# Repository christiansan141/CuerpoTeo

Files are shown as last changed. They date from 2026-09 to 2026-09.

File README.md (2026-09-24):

# TEO CONTROL R1 - Carcasa

Carcasa impresa en 3D para la tarjeta TEO CONTROL R1 (RPI-TK), controlador de fajon termico.
Disenada en Autodesk Fusion (documento CARA_TEO, carpeta CLAUDE).

## Archivos

| Archivo | Contenido |
|---|---|
| `CARA_TEO.f3d` | Archivo fuente de Fusion (historial parametrico completo) |
| `CARA_TEO.step` | Cara + cuerpo en STEP (intercambio CAD) |
| `stl/TEO_CARA_Y_CUERPO.stl` | Ambas piezas orientadas para imprimir |
| `stl/TEO_CARA.stl` / `stl/TEO_CUERPO.stl` / `stl/TEO_CONTRAMARCO.stl` | Piezas por separado |

## Especificaciones

- Material: PETG
- Altura total: 28 mm (cara 2 mm + cuerpo 26 mm); 15.4 mm libres bajo la PCB
- Cara: 60 x 121.8 mm, ventana OLED 24 x 14 mm con esquinas R1.5 y borde suavizado R0.6
- Interior: 122 mm de largo (incluye compartimento del convertidor AC-DC)
- Paredes y fondo: 2 mm
- Union cara-cuerpo: escalon (holgura 0.2 mm/lado) + 4 tornillos M3 con insertos termicos (piloto 4.0 mm, prof. 10 mm), simetricos a 4.5 mm de cada borde
- Barrera de 1.1 mm entre convertidor AC-DC y tarjeta
- Salidas de cables por el fondo: 4 ranuras de 7.5 mm (simetricas)
- Anclajes para brida en la salida de 120 V (borneras)
- Marco de sujecion continuo (10 mm hacia afuera, 3 mm de espesor), 12 mm bajo la cara, con 16 huecos de 4 mm y nervios a 45 grados por encima
- Contramarco de 3 mm con los mismos 16 huecos: se atornilla bajo el marco y pellizca la tela del fajon
- Agujeros para buzzer y rejillas de ventilacion en la franja expuesta

## Impresion

- Cara: superficie visible sobre la cama
- Cuerpo: fondo sobre la cama (el marco necesita soporte)
- `stl/CARA_CUERPO_TEO.stl`, `stl/CARA_TEO.stl`, `stl/CUERPO_TEO.stl`, `stl/AGARRE_TEO.stl`: ya orientados y apoyados en Z=0
- `CUERPO_TEO.stl` y `CARA_CUERPO_TEO.stl` traen soportes integrados bajo el marco: 148 aletas de 0.8 mm cada 2.5 mm,
  0.2 mm por debajo del marco y 0.6 mm separadas de la pared. Imprimir con los soportes del laminador desactivados
  y retirar las aletas a mano
- Insertos termicos M3 con cautin a ~240 C (PETG)

## Pendientes

- NFC embebido detras del QR (bolsillo interno + pausa de capa)
- Aislamiento Kapton/papel pescado entre convertidor y rele si hace falta

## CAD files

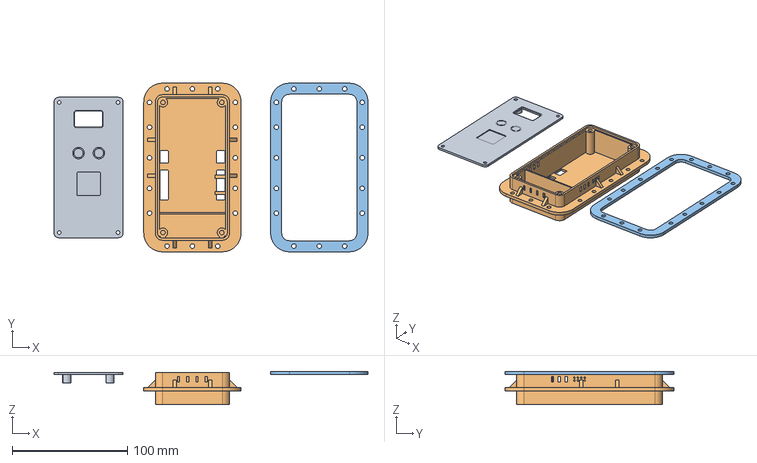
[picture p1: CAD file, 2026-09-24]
CARA_TEO.step
272.2 x 146.2 x 29.0 mm

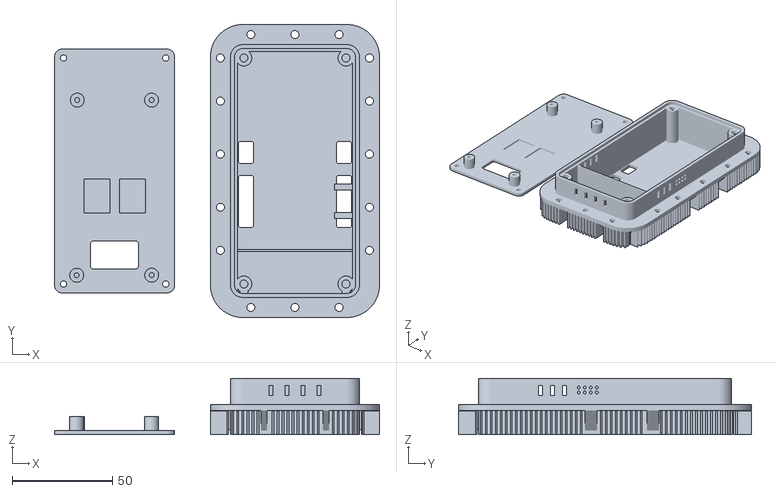
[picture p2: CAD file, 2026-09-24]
stl/CARA_CUERPO_TEO.stl
162.2 x 146.2 x 28.0

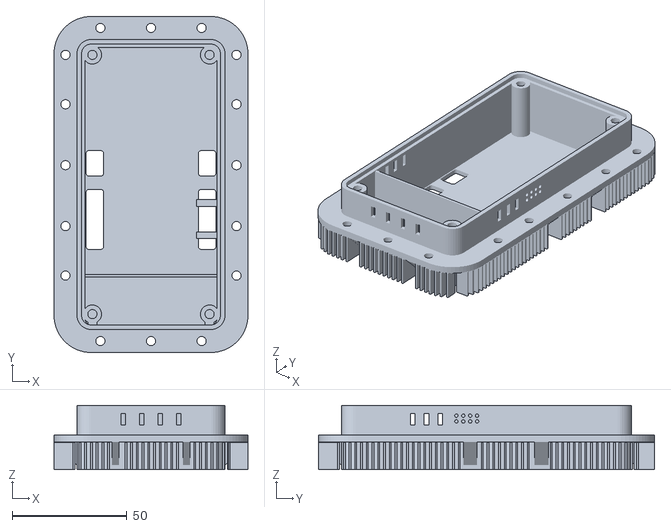
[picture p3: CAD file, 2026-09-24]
stl/CUERPO_TEO.stl
84.4 x 146.2 x 28.0

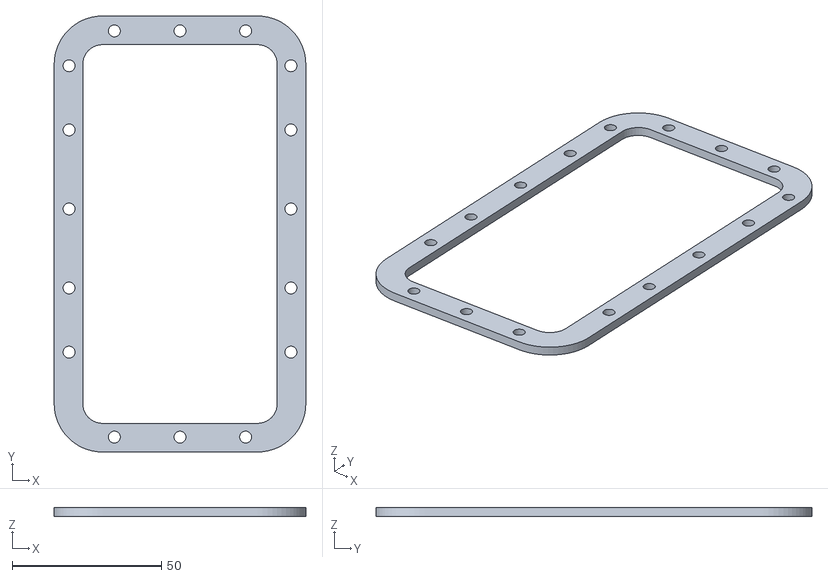
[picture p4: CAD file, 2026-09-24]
stl/AGARRE_TEO.stl
84.4 x 146.2 x 3.00

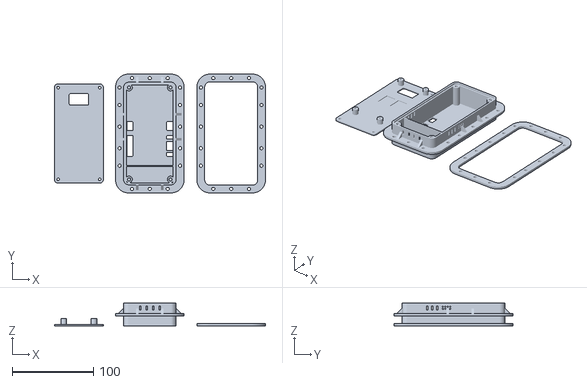
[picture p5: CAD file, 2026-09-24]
stl/TEO_CARA_Y_CUERPO.stl
259.4 x 146.2 x 28.0

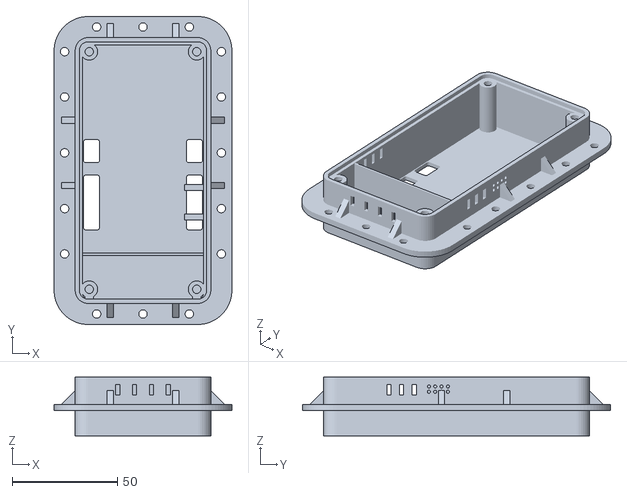
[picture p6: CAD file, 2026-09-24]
stl/TEO_CUERPO.stl
84.4 x 146.2 x 28.0

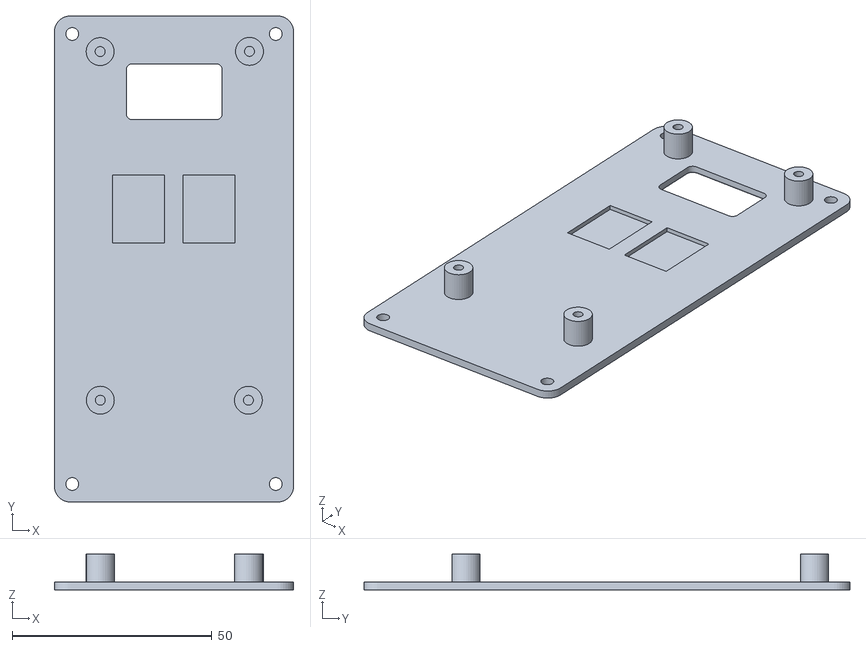
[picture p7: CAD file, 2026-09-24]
stl/TEO_CARA.stl
60.0 x 121.8 x 9.00

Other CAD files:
stl/TEO_CONTRAMARCO.stl
CARA_TEO.f3d
stl/CARA_TEO.stl

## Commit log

2026-09-24 Carcasa TEO CONTROL R1: cara + cuerpo (Fusion f3d, STEP, STL, README)
    [CARA_TEO.f3d, CARA_TEO.step, TEO_CARA.stl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]
2026-09-24 Paredes +2 mm (altura 28 mm) y marco de sujecion continuo
    [CARA_TEO.f3d, CARA_TEO.step, TEO_CARA_Y_CUERPO.stl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]
2026-09-24 Marco a 3 mm con 16 puntos de agarre, nervios por encima y nuevo contramarco
    [CARA_TEO.f3d, CARA_TEO.step, TEO_CARA_Y_CUERPO.stl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]
2026-09-24 STL listos para imprimir: cuerpo apoyado en Z=0 y cara girada 180 grados
    - CARA_CUERPO_TEO.stl: el cuerpo estaba 26 mm bajo la cama (se sube a Z=0);
    la cara estaba invertida (se gira 180 grados, superficie visible sobre la cama).
    - AGARRE_TEO.stl: sin cambios, ya estaba bien apoyado.
    Claude-Session: https://claude.ai/code/session_01BQYQ3tgGDgFaRiHw8cZ5eB
    [AGARRE_TEO.stl, CARA_CUERPO_TEO.stl]
2026-09-24 Separar CARA_CUERPO_TEO corregido en CARA_TEO.stl y CUERPO_TEO.stl
    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
    [CARA_TEO.stl, CUERPO_TEO.stl]
2026-09-24 Soportes integrados bajo el marco del cuerpo
    148 aletas verticales de 0.8 mm cada 2.5 mm, separadas 0.2 mm del marco y
    0.6 mm de la pared para retirarlas a mano. Se agregan a CUERPO_TEO.stl y
    CARA_CUERPO_TEO.stl; imprimir con soportes del laminador desactivados.
    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
    [CARA_CUERPO_TEO.stl, CUERPO_TEO.stl]
